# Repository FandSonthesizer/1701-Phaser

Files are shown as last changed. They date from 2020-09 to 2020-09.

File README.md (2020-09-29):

# 1701-Phaser 
This is a very nice phaser using a LM13700 OTA for the phasing effect, a LFO and some buffers to create the effect.
All run-of the-mill parts, fits into a 1590b enclosure and just sounds lovely.  
Check the demo on our youtube video blog for sound examples: https://www.youtube.com/channel/UCoEb9FIM5uLZekRLUyaKJfA

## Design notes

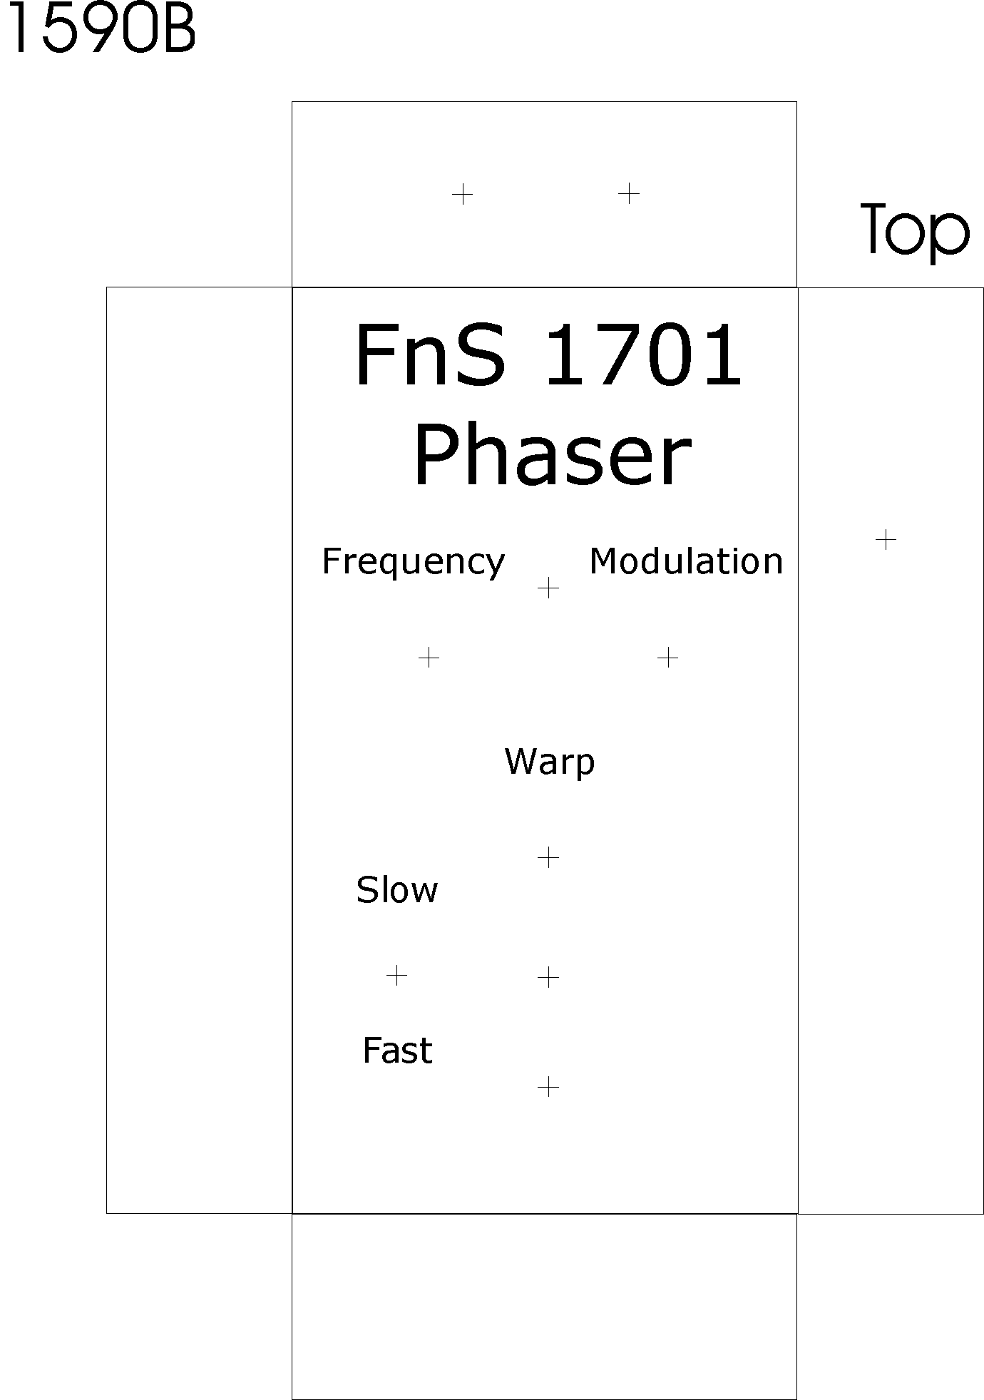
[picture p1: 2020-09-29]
FnS1701PhaserV2.0/FnS1701.TIF

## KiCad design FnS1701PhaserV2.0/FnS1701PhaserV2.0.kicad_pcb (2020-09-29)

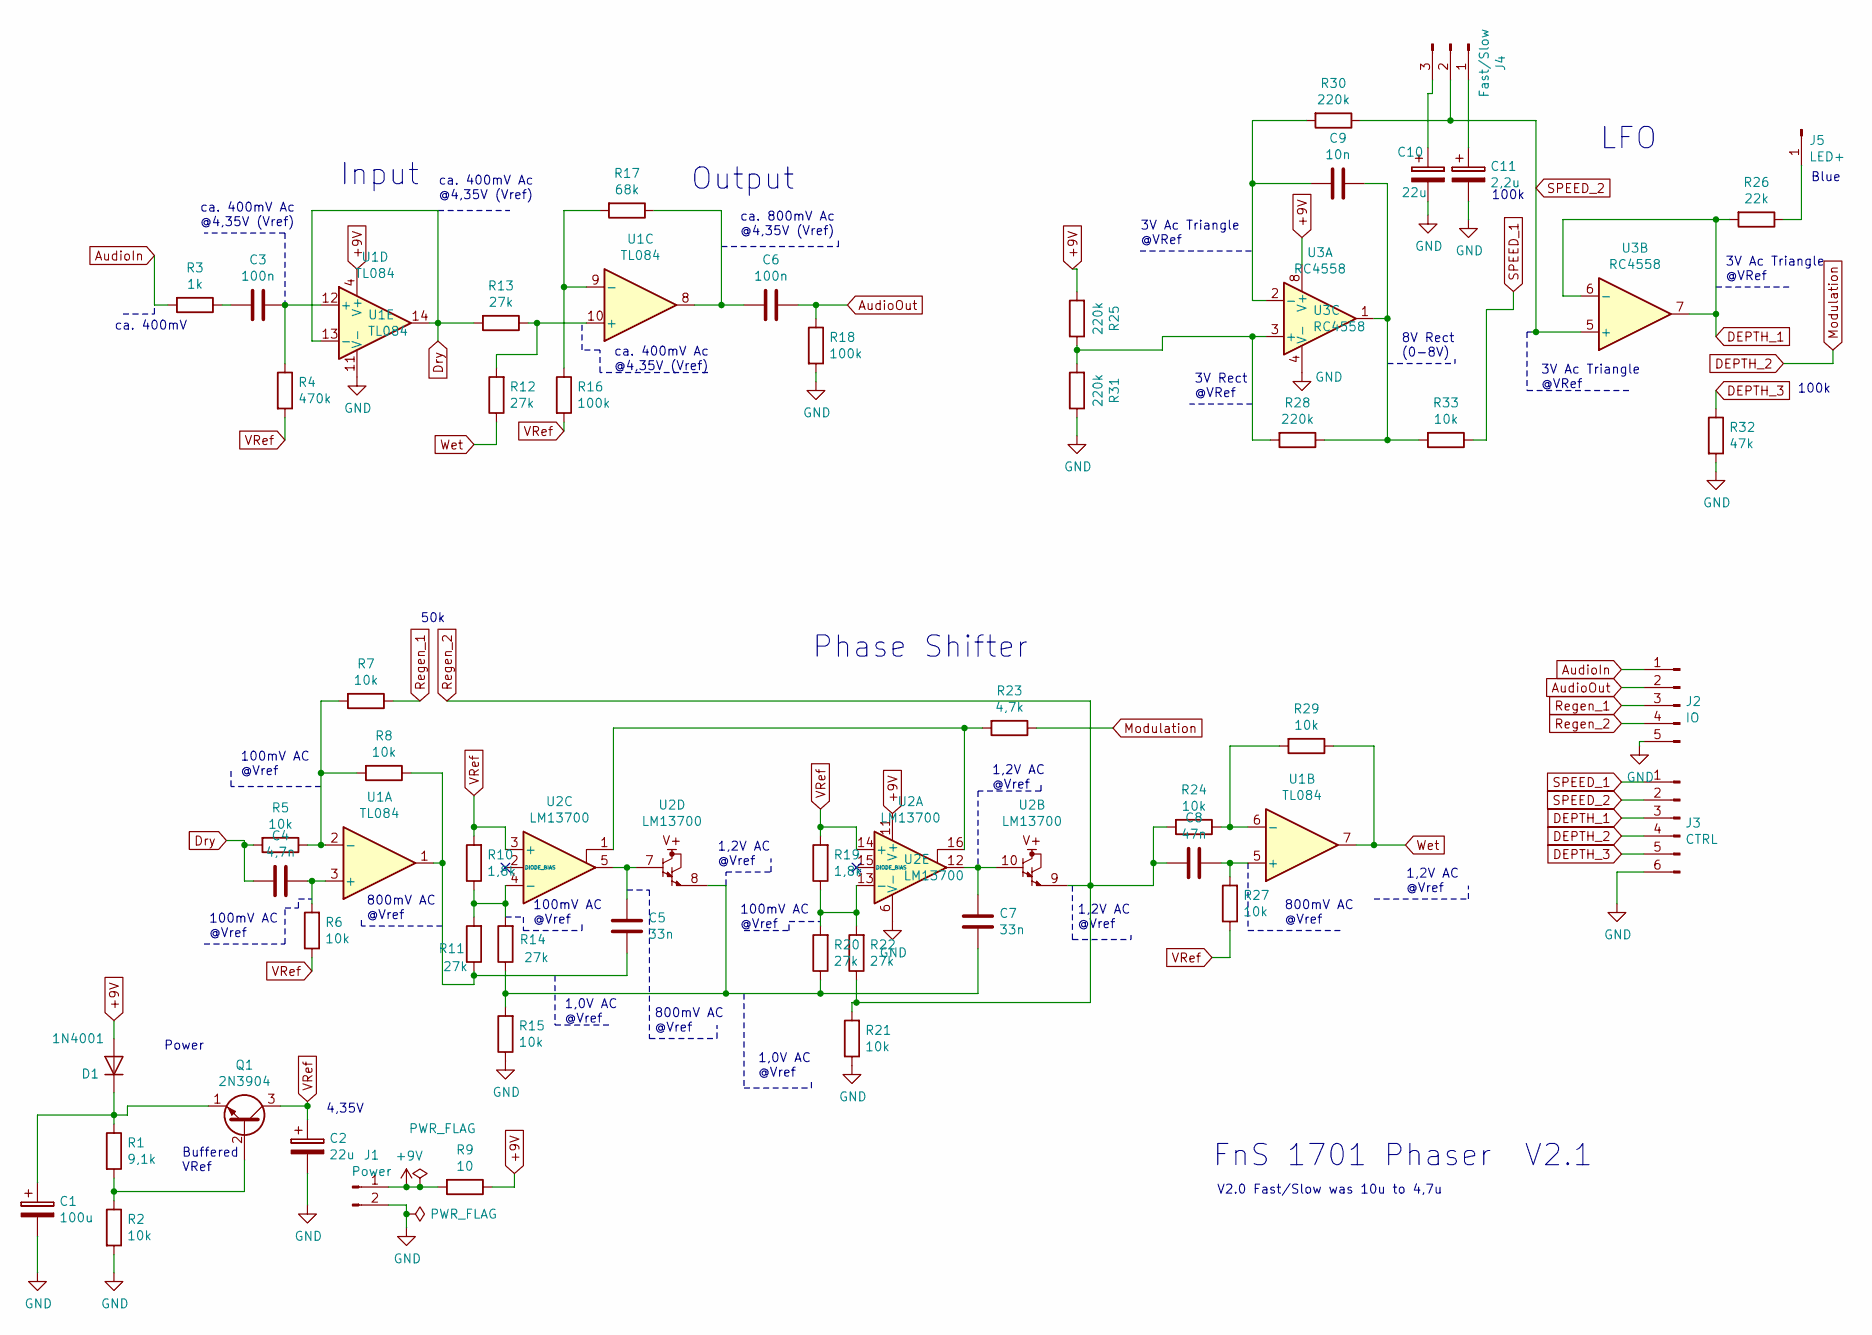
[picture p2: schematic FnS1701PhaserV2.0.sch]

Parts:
C1: 100u; Elko_D6.3mm_P2.50mm
C2, C10: 22u; Elko_D6.3mm_P2.50mm
C3, C6: 100n; Kondensator_Keramik
C4: 4,7n; Kondensator_Keramik
C5, C7: 33n; Kondensator_Keramik
C8: 47n; Kondensator_Keramik
C9: 10n; Kondensator_Keramik
C11: 2,2u; Elko_D6.3mm_P2.50mm
D1: 1N4001; Diode_Horizontal
J1: Power; Stift_x02
J2: IO; PinHeader_1x05_P2.54mm_Vertical
J3: CTRL; PinHeader_1x06_P2.54mm_Vertical_NIK
J4: Fast/Slow; Stift_0x3
J5: LED+; Stift
Q1: 2N3904; TO-92_Wide_NIK
R1: 9,1k; Widerstand_liegend
R2, R5, R6, R7, R8, R15, R21, R24, R27, R29, R33: 10k; Widerstand_liegend
R3: 1k; Widerstand_liegend
R4: 470k; Widerstand_liegend
R9: 10; Widerstand_liegend
R10, R19: 1,8k; Widerstand_liegend
R11, R12, R13, R14, R20, R22: 27k; Widerstand_liegend
R16, R18: 100k; Widerstand_liegend
R17: 68k; Widerstand_liegend
R23: 4,7k; Widerstand_liegend
R25, R28, R30, R31: 220k; Widerstand_liegend
R26: 22k; Widerstand_liegend
R32: 47k; Widerstand_liegend
U1: TL084; DIP-14_W7.62mm_Socket_LongPads
U2: LM13700; DIP-16_W7.62mm_Socket_LongPads
U3: RC4558; DIP-8_W7.62mm_Socket_LongPads

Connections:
+9V: D1.2 (A), J1.1, R9.1, R9.2, R25.2, U1.4 (V+), U2.11 (V+), U3.8 (V+)
AudioIn: J2.1, R3.2
AudioOut: C6.1, J2.2, R18.1
DEPTH_1: J3.3, R26.2, U3.6 (-), U3.7
DEPTH_2: J3.4, R23.1
DEPTH_3: J3.5, R32.1
Dry: C4.2, R5.2, R13.2, U1.13 (-), U1.14
GND: C1.2, C2.2, C10.2, C11.2, J1.2, J2.5, J3.6, R2.2, R15.1, R18.2, R21.1, R31.1, R32.2, U1.11 (V-), U2.6 (V-), U3.4 (V-)
unnamed: C1.1, D1.1 (K), Q1.1 (E), R1.1
unnamed: C3.1, R4.1, U1.12 (+)
unnamed: C3.2, R3.1
unnamed: C4.1, R6.2, U1.3 (+)
unnamed: C5.1, R8.1, R11.1, U1.1
unnamed: C5.2, U2.5, U2.7
unnamed: C6.2, R17.1, U1.8
unnamed: C7.1, R14.1, R15.2, R20.1, U2.8
unnamed: C7.2, U2.10, U2.12
unnamed: C8.1, R27.2, U1.5 (+)
unnamed: C9.1, R28.1, R33.2, U3.1
unnamed: C9.2, R30.2, U3.2 (-)
unnamed: C10.1, J4.3
unnamed: C11.1, J4.1
unnamed: J5.1, R26.1
unnamed: Q1.2 (B), R1.2, R2.1
unnamed: R5.1, R7.2, R8.2, U1.2 (-)
unnamed: R10.1, R11.2, R14.2, U2.4 (-)
unnamed: R12.2, R13.1, U1.10 (+)
unnamed: R16.1, R17.2, U1.9 (-)
unnamed: R19.1, R20.2, R22.2, U2.13 (-)
unnamed: R23.2, U2.1, U2.16
unnamed: R24.1, R29.2, U1.6 (-)
unnamed: R25.1, R28.2, R31.2, U3.3 (+)
Regen_1: J2.3, R7.1
Regen_2: C8.2, J2.4, R21.2, R22.1, R24.2, U2.9
SPEED_1: J3.1, R33.1
SPEED_2: J3.2, J4.2, R30.1, U3.5 (+)
VRef: C2.1, Q1.3 (C), R4.2, R6.1, R10.2, R16.2, R19.2, R27.1, U2.3 (+), U2.14 (+)
Wet: R12.1, R29.1, U1.7

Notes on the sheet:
Input
Output
Power
LFO
Phase Shifter
FnS 1701 Phaser V2.1
100k
50k
4,35V
ca. 400mV
ca. 400mV Ac @4,35V (Vref)
ca. 800mV Ac @4,35V (Vref)
3V Ac Triangle @VRef
8V Rect (0-8V)
3V Rect @VRef
Buffered VRef
100mV AC @Vref
800mV AC @Vref
1,2V AC @Vref
1,0V AC @Vref
Blue
V2.0 Fast/Slow was 10u to 4,7u

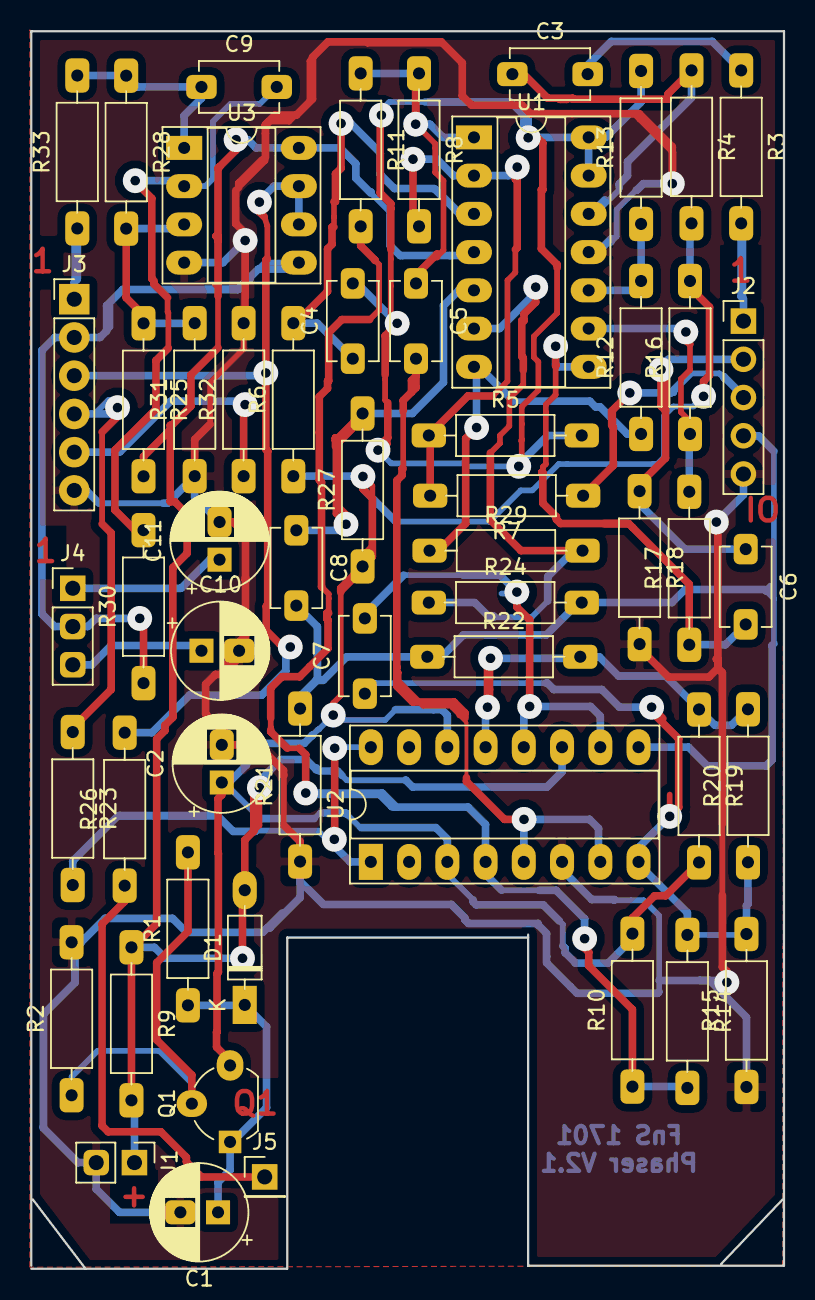
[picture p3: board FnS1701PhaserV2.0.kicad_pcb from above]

Board: 2 copper layers, 50.0 x 82.2 mm, 54 parts (0 on the bottom side), 38 nets.
